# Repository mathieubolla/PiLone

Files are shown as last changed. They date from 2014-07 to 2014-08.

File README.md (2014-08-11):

PiLone
======

PiLone is Open Source HardWare that allows quietly displaying various quantitative and/or time based data in the living room

DISCLAIMER
==========

BEWARE: This is currently a barely functionnal proto

BEWARE BEWARE: The provided PCB hasn't been fabed currently. Do not mass order one, it may not even work...

The provided software and attached hardware designs are provided as-is, with no waranty at all. It may catch fire, it may destroy components, it may not function as advertised, it hasn't been certified for anything (No CE markings, no FCC markings...). Take extreme care when using either software or hardware designs and make sure you fully understand the software and hardware before doing anything with it. You've been warned.

Made with...
============

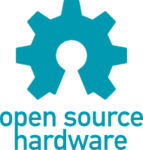
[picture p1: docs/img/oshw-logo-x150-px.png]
OpenSource HardWare logo (http://www.oshwa.org)

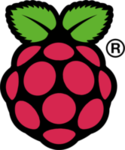
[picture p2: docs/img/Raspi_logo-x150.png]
Raspberry Pi Logo (http://www.raspberrypi.org/)

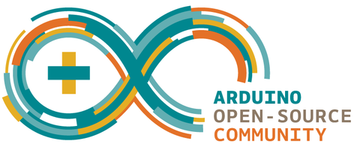
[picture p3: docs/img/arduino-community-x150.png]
Arduino Community Logo (http://www.arduino.cc)


Raspberry Pi is a trademark of the Raspberry Pi Foundation

Arduino Community is a trademark of Arduino SA

Licence
=======

All software in this repository is released under the GNU General Public Licence V3.0. You may find a copy online [there](http://opensource.org/licenses/GPL-3.0) or localy [here](./software-licence.txt)

All documentation, drawings, pictures, schematics, and more generaly all that is not a computer program or part of it is licenced under the Creative Commons CC-BY-SA V4.0 licence. You may find a copy of the licence [there](http://creativecommons.org/licenses/by-sa/4.0/) or localy [here](./hardware-licence.txt)

What is it?
===========

What's in here?
---------------

In this project, you will find how to plug a Raspberry Pi, an Arduino Pro Mini, and some Adafruit NeoPixels together, to make a connected object that can display time based, or quantitative, information in a beautifull way.

The two most important parts are:

- Some software to gather data and push it to pixels
- A custom PCB to hold the parts together

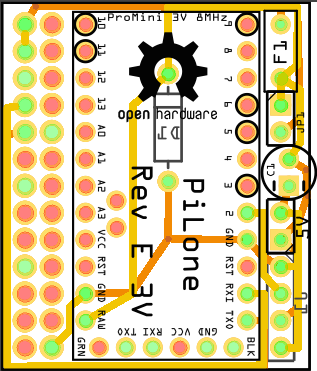
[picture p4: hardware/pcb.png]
The custom PiLone PCB


What can I build with it?
-------------------------

With those hardware designs and software, you may build a pretty connected object that displays various informations on LED strips, with all the ugly electronics parts encased in a PlexiGlass tube about 11cm diameter by 18cm height.

What information it may display depends entierly on your imagination, and programming skills. But here are two samples, provided in the sample software:

### Visual alarm clock

You may want a visual reminder of something in time, like, the hour at which your eldest child should leave to school. PiLone will start lighting its LED one by one ten minutes before the expected time, and then blink for five minutes when you're late. Now, he can't be late anymore: The more light you see, the more motivated he will be.

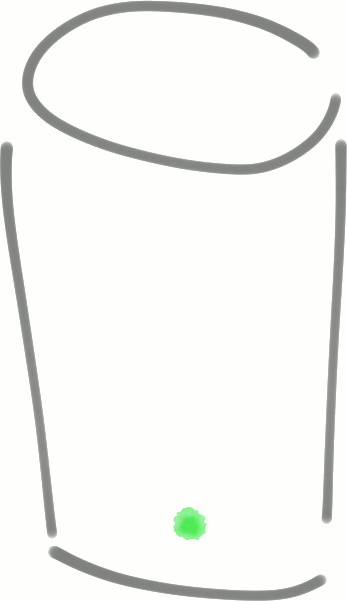
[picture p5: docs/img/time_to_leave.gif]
Time to leave illustration


### Differential meteo

You may also want to know if you need an umbrella or your super insulating coat. But what's the point in pulling your very smart phone to know it's 18°C outside? Is it cold? And do you have time to do so? You'd better visually know if today is colder than yesterday, and with less rain. Differential meteo just does that: Display one or two, red or blue, dots for temperature, one for slighly different, two for really different, red for hotter, blue for warmer. And three light blue dots for the rain. One for light, two for serious, three for the apocalypse. Now, you just know: Umbrella, no coat.

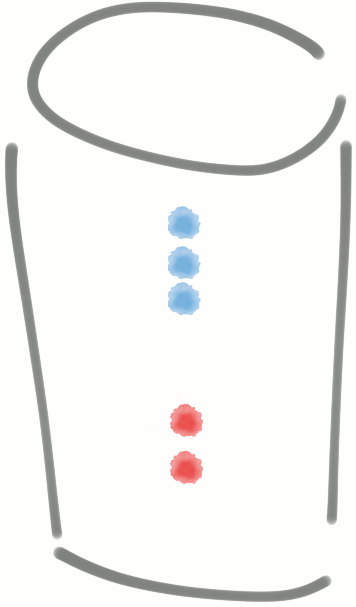
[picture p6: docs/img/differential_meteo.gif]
Differential meteo illustration


### Combine them

Because your PiLone is made of sticks, three of them, you can choose which is better for the task. Lets say, meteo closer to the umbrella, and alarm clock from your kitchen table. So you see what you need where your need it. But there's more: Each stick is independent. That means, if you need the meteo while your son need alarm clock, just display both.

Why?
====

I started this project when I realized I wanted something able to push some information to me, silently, quietly, not on my phone, nor my computer. Something the old Nabaztag did perfectly until it died, and without the bugs.

I already had, as most of my fellow geek friends, a Raspberry Pi. I wanted to learn some Arduino to understand the buzz. And I liked the way NeoPixel sticks can display efficiently information. I had to plug it all together.

Requirements
============

Hardware parts
--------------

Raspberry Pi and SD card:

- 1x Raspberry Pi model B rev. 2 ([SparkFun](https://www.sparkfun.com/products/11546))
- 1x SD-Card (any size will do, as long as your Linux fits in. >4Gb recommended)

Arduino and PCB:

- 1x SparkFun Arduino Pro Mini 3v 8MHz ([SparkFun](https://www.sparkfun.com/products/11114))
- 1x custom made PCB (you may have the one [here](./hardware/PiLone%20rev%20E%203v%20low%20spec.fzz) made at Fritzing Fab, for instance, or build it - yourself if you have time, patience, skills, and something to print, cut, drill small, two-sided PCBs)
- 1x 2x13, 0.1' spaced, shrouded header ([SparkFun](https://www.sparkfun.com/products/11490)) OR 2x13, 0.1' spaced, female header ([SparkFun](https://www.sparkfun.com/products/11765)) (BEWARE: Shrouded header is NOT Raspberry Pi B+ compatible)

Power supply:

- 1x 5V 2A 3.5mm power supply ([SparkFun](https://www.sparkfun.com/products/12889))
- 1x 3.5mm power jack socket ([SparkFun](https://www.sparkfun.com/products/119)) OR 3.5mm panel mount power jack socket ([SparkFun](https://www.sparkfun.com/products/10785))
- 1x 2-pin JST 100mil jumper wire ([SparkFun](https://www.sparkfun.com/products/10362))

LED strips:

- 3x Adafruit Technology High Density NeoPixel Sticks (or less, at least one) (or any other WS-2812 controlled 5050 RGB LED strip or - stick) ([SparkFun](https://www.sparkfun.com/products/12661))
- 6x 4-pin, 0.1' spaced, male pins ([SparkFun](https://www.sparkfun.com/products/116))
- 3x 4-pin, 0.1' spaced, female-to-wire cables ([SparkFun](https://www.sparkfun.com/products/10364))

Optionnal (highly recommended) RaspberryPi power protection circuit:

- 1x 220uF decoupling capacitor (any big enough will do, for instance [SparkFun](https://www.sparkfun.com/products/96))
- 1x 1100mA polyfuse (hard to find) OR a 100mil jumper ([SparkFun](https://www.sparkfun.com/products/9044))
- 1x 1A rectifier diode (be prepared to fry it if you use more powerfull power supply AND plug it reversed) ([SparkFun](https://www.sparkfun.com/products/8589))

Optionnal (recommended):

- 1x FTDI-to-USB converter (SparkFun's works perfectly, any clone will do) ([SparkFun](https://www.sparkfun.com/products/9716) or get a friend to program your Arduino for you)
- Some soldering material and tooling

Total expected bill: under 100€ including taxes and customs, depending on shipping costs (group your packages!)

(as of 11th of August 2014, all on SparkFun, USD 99.80 exc. shipping and taxes, plus custom PCB EUR 7.11 exc. shipping)

Software parts
--------------

- Linux installed on the SD-Card (any standard distribution will do, tested on Raspbian)
- Python 2.7.x (most probably already installed)
- PySerial (install with `pip install pyserial`)
- [optional] BottlePy (intall with `pip install bottle`) (if you need test.py to play with LED colors by hand, to check your hardware is well built)
- UART console disabled, reconfigured as serial port ([Tooling and manual there](https://github.com/lurch/rpi-serial-console))
- [optional] [Fritzing](http://fritzing.org/home/) to work on PCB design
- [optional] [SketchUp](http://www.sketchup.com) to work on case design and see real world assembly

TODO
====

Comming next are some instructions on how to assemble the thing (have a look at the provided breadboard view to get a glimpse)

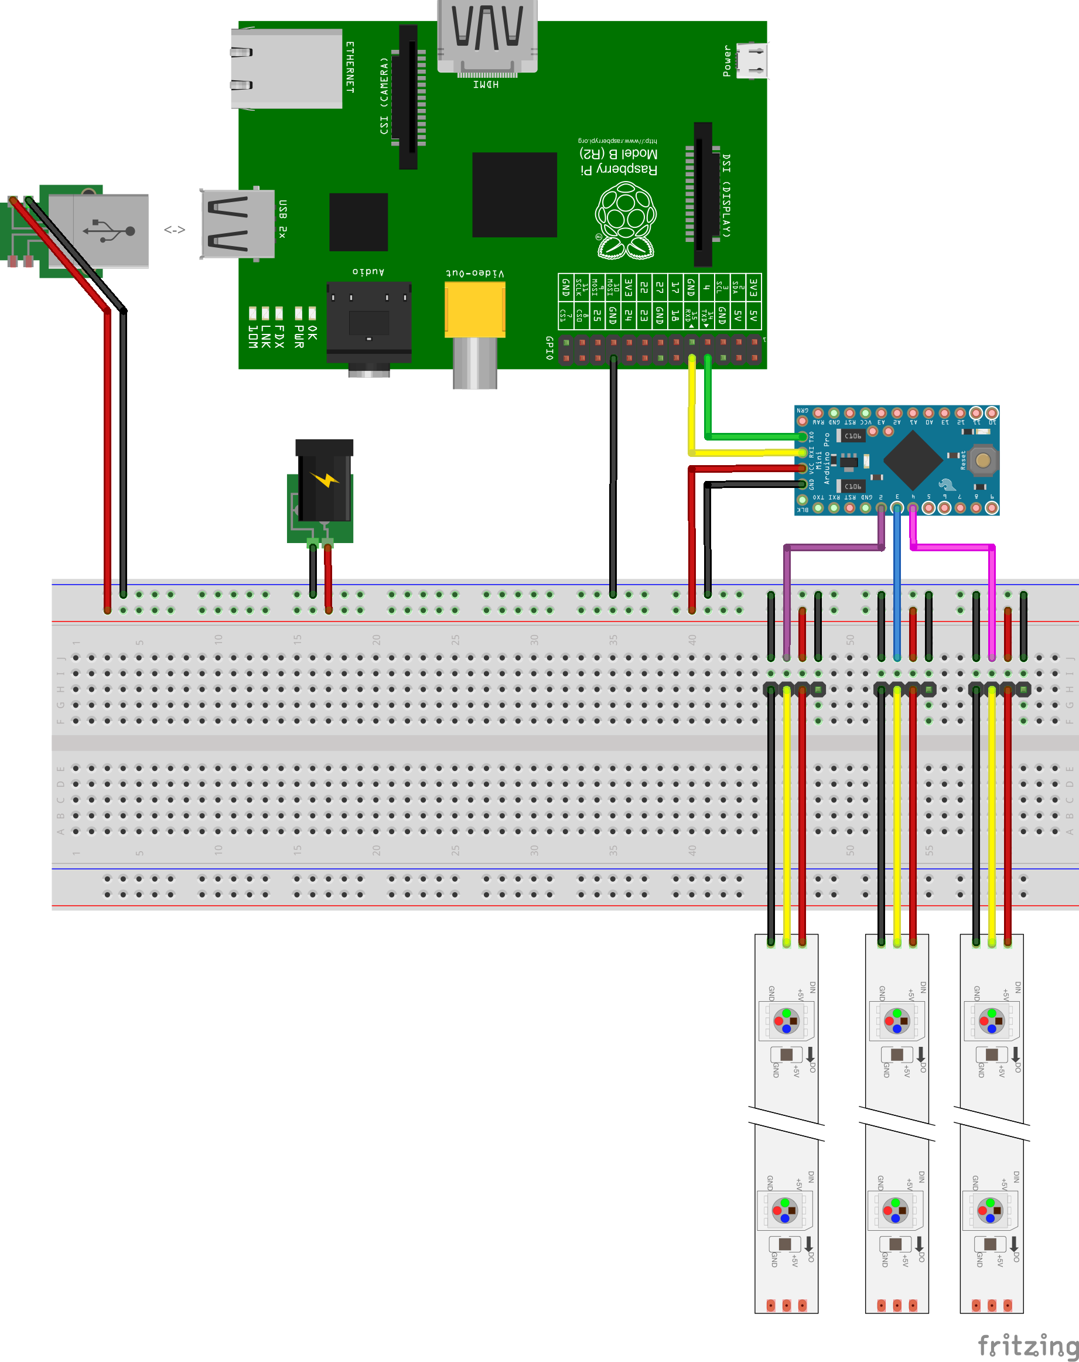
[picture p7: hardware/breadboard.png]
Breadboard view


Then, some more on how to run it

Then, something on the software architecture and what could be done with it really easily

Finally, a better designed (completed design? 3d-printable, laser cut?) case to hold it

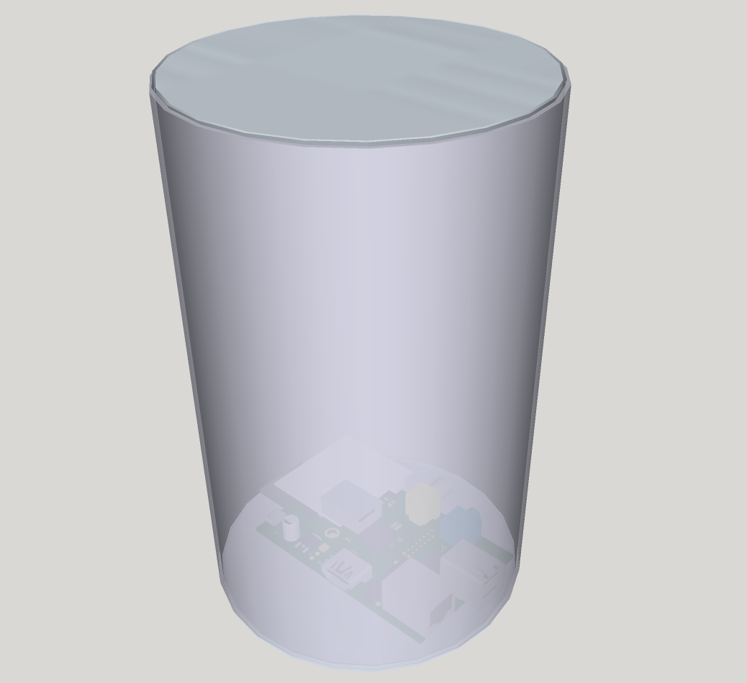
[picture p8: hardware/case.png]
Case view


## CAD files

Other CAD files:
PiLone.skp
hardware/PiLone.skp

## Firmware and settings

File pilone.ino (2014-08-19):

// author 'Mathieu Bolla'
// copyright 'Copyright 2014, Mathieu Bolla'
// licence 'GPL V3.0'

#include <Adafruit_NeoPixel.h>

Adafruit_NeoPixel strip = Adafruit_NeoPixel(24, 2, NEO_GRB + NEO_KHZ800);
String inputString = "";
boolean stringOk = false;
boolean talking = true;
int stepping = 0;
unsigned int transitions[24][9];
unsigned long lastTime = millis();
#define STEPS 63

void setup() {
  Serial.begin(57600);
  inputString.reserve(20);
  
  strip.begin();
  strip.setBrightness(255); // Half power
  strip.show(); // Initialize all pixels to 'off'
}

void loop() {
  if (talking) {
    if (stringOk) {
      int checksum = 0x0;
      for (int i = 0; i < inputString.length(); i++) {
        int charAtI = inputString.charAt(i);
        checksum ^= charAtI;
      }
      Serial.println(String(checksum, HEX));
      
      int ledId = decodeHex(inputString.substring(0, 2));
      for (int i = 0; i <= 10; i += 2) {
        int value = decodeHex(inputString.substring(i+2, i+4));
        transitions[ledId][i / 2] = value;
      }
      
      stringOk = false;
      inputString = "";
      
      talking = false;
    }
  } else {
    unsigned long currentTime = millis();
    if (currentTime - lastTime > 10 || currentTime - lastTime < 0) {
      lastTime = currentTime;
      showData();
    }
  }
}

void showData() {
  if (stepping < STEPS) {
    showDataAt(0, 3, stepping);
  } else {
    showDataAt(3, 0, stepping - STEPS);
  }
  stepping++;
  if (stepping > 2 * STEPS) {
    stepping = 0;
  }
}

void showDataAt(int k, int k2, int steps) {
      for (int j = 0; j < 24; j++) {
        int red = transitions[j][k];
        int green = transitions[j][k+1];
        int blue = transitions[j][k+2];
        
        int targetRed = transitions[j][k2];
        int targetGreen = transitions[j][k2+1];
        int targetBlue = transitions[j][k2+2];
        
        int deltaRed = targetRed - red;
        int deltaGreen = targetGreen - green;
        int deltaBlue = targetBlue - blue;
        
        strip.setPixelColor(j, strip.Color(red + deltaRed * steps / STEPS, green + deltaGreen * steps / STEPS, blue + deltaBlue * steps / STEPS));
      }
      strip.show();
}

void serialEvent() {
  talking = true;
  while (Serial.available()) {
    char inChar = (char)Serial.read();
    inputString += inChar;
    if (inChar == '\n') {
      stringOk = true;
    }
  }
}

int decodeHex(String hex) {
  int results = 0;
  
  char highOrder = hex.charAt(0);
  char lowOrder = hex.charAt(1);
  
  if(highOrder > 58) {
    results += (highOrder - 65 + 10) * 16;
  } else {
    results += (highOrder - 48) * 16;
  }
  
  if(lowOrder > 58) {
    results += lowOrder - 65 + 10;
  } else {
    results += lowOrder - 48;
  }
  
  return results;
}

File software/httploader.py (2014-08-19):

__author__ = 'Mathieu Bolla'
__copyright__ = 'Copyright 2014, Mathieu Bolla'
__licence__ = 'GPL V3.0'

import time

class Task():
    time = None
    where = None

    def __init__(self, time, where):
        self.time = time
        self.where = where

    def schedule(self):
        return self.time

    def where_is(self):
        return self.where

    def process(self, tasks, strand):
        print 'Reading colors from ', self.where_is()
        from_app = read_from_app(self)

        for line in from_app['data']:
            strand.print_color(line['led'], line['color1'], line['color2'])

class Planning():
    where = None
    time = None

    def __init__(self, where, delta = 0):
        self.time = time.time() + delta
        self.where = where

    def schedule(self):
        return self.time

    def where_is(self):
        return self.where

    def process(self, tasks, strand):
        print 'Reading planing from ', self.where_is()
        from_url = read_from_url(self.where_is())
        from_url_tasks_ = from_url['tasks']
        planning = Planning(self.where_is(), 30)

        tasks.put((planning.schedule(), planning))

        for from_url_task_ in from_url_tasks_:
            print 'Pushing a task on queue'
            tasks.put((from_url_task_[0], Task(from_url_task_[0], from_url_task_[1])))

def read_from_url(url):
    import urllib2

    value = None

    while value == None:
        try:
            req = urllib2.Request(url)
            resp = urllib2.urlopen(req)
            value = resp.read()
        except urllib2.URLError:
            pass

    import json
    from StringIO import StringIO

    return json.load(StringIO(value))

def read_from_app(task):
    return read_from_url(task.where_is())

def main(args):
    import strand
    import serial
    import Queue

    strand = strand.Strand(serial.Serial('/dev/ttyAMA0', 57600, timeout=1))
    tasks = Queue.PriorityQueue()
    planning = Planning('http://pilone/')
    tasks.put((planning.schedule(), planning))

    for i in range(0, 7):
        strand.print_color(i, "000000", "000000")

    while True:
        scheduled, task = tasks.get()
        wait_time_ = task.schedule() - time.time()
        time.sleep(wait_time_ if wait_time_ > 0 else 0)
        task.process(tasks, strand)

if __name__ == '__main__':
    import sys
    main(sys.argv[1:])

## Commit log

2014-06-19 Initial prototype: Accepts individual color settings
2014-07-07 Added 3d rendering, added PCB draft, modified strandtest3.ino type
    [PiLone.skp, Strander.fzz]
2014-07-08 Readying for production
    [PiLone rev C.fzz, Strander.fzz]
2014-07-08 Add raspberry pi logo Add oshwa website
2014-07-08 Moved files into place
    [PiLone rev C.fzz, PiLone.skp]
2014-07-08 Arduino Community logo
2014-07-08 Add custom PCB image
2014-07-08 Add case
2014-07-09 Added NeoPixel strips to breadboard picture
    [PiLone rev C with strips.fzz]
2014-07-09 Some samples
2014-07-30 Added RevC 3V low spec. BEWARE: This PCB has a bug, you should NOT connect VCC pin on the 6 pin serial headers of the Pro Mini, which should be powered by its RAW pin instead
    [PiLone rev C 3v low spec.fzz]
2014-08-06 Introduce 3V Revision D: Powers the raw pin instead of VCC, move connectors to accommodate
    [PiLone rev D 3v low spec.fzz]
2014-08-06 Added fuse, diode, capacitor to supply Raspberry Pi via 5V rail directly
    [PiLone rev D 3v low spec.fzz]
2014-08-11 Introduce PiLone rev E 3v low spec: Feeds the Raspberry Pi by protected 5v circuit, has only 1 LED strip connector (requires specific firmware to daisy chain 3 strips)
    [PiLone rev E 3v low spec.fzz]
2014-08-11 Add some drawings
    [PiLone.skp]
2014-08-11 PCB rev E image
2014-08-11 Update read me with new PCB
2014-08-11 Updated bill of material
2014-08-19 No idea, binary differences?
    [PiLone rev E 3v low spec.fzz]
